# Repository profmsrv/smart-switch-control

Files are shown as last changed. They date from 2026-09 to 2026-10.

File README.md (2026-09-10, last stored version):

🏠 SmartHomePro
A smart home automation system built using ESP8266 and RS485 for reliable and scalable home control.

✨ Features
Wi-Fi based device control
ESP8266 based controllers
RS485 communication
Mobile and Web control
Physical switch control
Energy monitoring
Optional Firebase cloud integration
Secure user authentication
Scalable relay control
Local hotspot mode
⚙️ Technology
Microcontroller: ESP8266
Communication: RS485
Cloud: Firebase
Connectivity: Wi-Fi
Control: Mobile, Web & Physical Switches
🏗️ How It Works
The main ESP8266 controller communicates with multiple sub-controllers using RS485. Each sub-controller controls connected electrical loads through relays.

Mobile / Web
│
Wi-Fi
│
Main Controller
ESP8266
│
RS485
│
┌───┼────┬────┐
│ │ │ │
Sub Sub Sub Sub
│ │ │ │
Relay Relay Relay Relay
│ │ │ │
Loads Loads Loads Loads
⚡ Energy Monitoring
Monitor current and power consumption of connected electrical loads to understand usage and improve energy efficiency.

☁️ Firebase
Optional Firebase integration allows remote control, authentication, and real-time system monitoring from anywhere.

🚀 Getting Started
Clone this repository.
Open the ESP8266 project in Arduino IDE.
Install the required libraries.
Configure Wi-Fi and Firebase settings.
Upload the firmware to the ESP8266.
Connect the controllers using RS485.
Connect and configure the relay outputs.
⚠️ Safety
This project may involve high-voltage electrical systems. Electrical wiring and installation should only be performed by a qualified professional.

📌 Project Status
🚧 Under Development

❤️ About
SmartHomePro is designed to provide reliable, scalable, and energy-efficient smart home automation using affordable embedded hardware.

Made with ❤️ in India 🇮🇳

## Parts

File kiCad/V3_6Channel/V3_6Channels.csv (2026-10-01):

item number | Designator | Qty | Description_1 | MP | Package | Value | Assembly Instructions
1 | C1,C2 | 2 | 22 pF ±2% 50V Ceramic Capacitor C0G, NP0 0603 (1608 Metric) | CC0603GRNPO9BN220 | 0603 Yageo | crystal_cap
2 | C3 | 1 | 100nF±10% 10Vdc General Purpose Caps X7R 0402 (1005 Metric) | 0402B104K100CT | 402-2 WALSIN | vcc_de_cap
3 | C4 | 1 | 100nF±10% 10Vdc General Purpose Caps X7R 0402 (1005 Metric) | 0402B104K100CT | 402-2 WALSIN | avcc_de_cap
4 | C5 | 1 | 100nF±10% 10Vdc General Purpose Caps X7R 0402 (1005 Metric) | 0402B104K100CT | 402-2 WALSIN | aref_de_cap
5 | C6 | 1 | 100nF±10% 10Vdc General Purpose Caps X7R 0402 (1005 Metric) | 0402B104K100CT | 402-2 WALSIN | rst_de_cap
6 | C7 | 1 | 100nF±10% 10Vdc General Purpose Caps X7R 0402 (1005 Metric) | 0402B104K100CT | 402-2 WALSIN | max_de_cap
7 | C8 | 1 | 100nF±10% 10Vdc General Purpose Caps X7R 0402 (1005 Metric) | 0402B104K100CT | 402-2 WALSIN | uln_de_cap
8 | C9,C10,C11,C12,C13,C14 | 6 | ALU Electrolytic, SMD, EXV, +105°C, 25VDC, 5µF, 5 x 5.4 | KEMET EXV226M025A9DAA | EXV226M025A9DAA | Radial KEMET | AC Ripple Filter
9 | D1 | 1 | 600W, 15V, Bidirectional, TVS | SMBJ15CA | SMB Taiwan Semiconductor | SMBJ15CA
10 | J1,J11,J12 | 3 | Connector Header Through Hole 6 position 0.100 (2.54mm) | 61300611121 | None | 61300611121
11 | J2,J13 | 2 | Connector Header Through Hole 2 position 0.100 (2.54mm) | 61300211121 | None | 2Pin_jumper
12 | J3 | 1 | TERMI-BLOK PCB SIDE ENTRY STAC | TE Connectivity 284391-3 | 284391-3 | None | 284391-3
13 | J5 | 1 | 7 pins, 1 row, straight, gold plating | 61300711121 | None | 61300711121
14 | J14 | 1 | 6 Position Wire to Board Terminal Block Horizontal with Board 0.200 (5.08mm) Through Hole | 282837-6 | None | 282837-6
15 | P1 | 1 | Terminal Block Connector Wire Receptacle 2 5.08 mm 30-16 AWG Green 13.5 A 250 V | TE Connectivity 282837-2 | 282837-2 | None | AC IN
16 | PS1 | 1 | The HLK-PM01 is a small size low cost AC to DC converter which can take in 110V/220V AC at 50/60 Hz and give 5V 3W output. The module is can be used in designs which run on 5V and needs to be powered form the AC mains. | hlk-pm01 | None | HLK-PM01
17 | Q1 | 1 | 50-V, 7-ch darlington transistor array, -20C to 70C | ULN2003AN | PDIP-16 Texas Instruments | ULN2003AN
18 | R1,R5,R6,R11,R12,R15,R16,R19,R20,R23,R24,R27,R28 | 13 | Res Thick Film 0805 10K Ohm 5% 0.125W(1/8W) 200ppm/C Pad SMD Automotive T/R | RMCF0805JT10K0 | 0805 | 10k
19 | R2 | 1 | Res Thick Film 1206 120 Ohm 1% 0.25W 100ppm/C Molded SMD Paper T/R | RMCF1206FT120R | 1206 | 120
20 | R3,R4 | 2 | """Fixed Resistor, Thin Film, 0.25W, 10ohm, 200V, 1% +/-Tol, 100ppm/Cel, Surface Mount, 0805""" | RNCP0805FTD10R0 | 0805 | 10
21 | R7,R8,R9,R10,R13,R14,R17,R18,R21,R22,R25,R26 | 12 | 27.4 kOhms ±0.5% 1W Chip Resistor 1206 (3216 Metric) Anti-Sulfur, Automotive AEC-Q200, Moisture Resistant Thin Film | HRG3216P-2702-D-T1 | 3216 Susumu | HRG3216P-2702-D-T1
22 | U1 | 1 | 1/1 Transceiver Half RS422, RS485 8-SOIC | MAX485ESA+ | SOIC-8 Maxim | MAX485ESA_
23 | U2,U4,U5,U6,U7,U8 | 6 | Optoisolator Transistor with Base Output 4170Vrms 1 Channel 6-DIP | H11AA1M | PDIP-6 ON Semiconductor | H11AA1M
24 | U3 | 1 | MCU 8-bit - AVR ATmega Family ATmega328 Series Microcontrollers - 20 MHz - 32 KB - 2 KB - 32 Pins. | ATMEGA328P-AU | TQFP-32 Microchip | ATMEGA328P-AU
25 | Y1 | 1 | Crystal 16MHz ±10ppm (Tol) ±20ppm (Stability) 18pF FUND 70Ohm 4-Pin Ultra Mini-CSMD T/R | ABM8-16.000MHZ-D1X-T | NON-STANDARD-4 ABRACON | 16MHz

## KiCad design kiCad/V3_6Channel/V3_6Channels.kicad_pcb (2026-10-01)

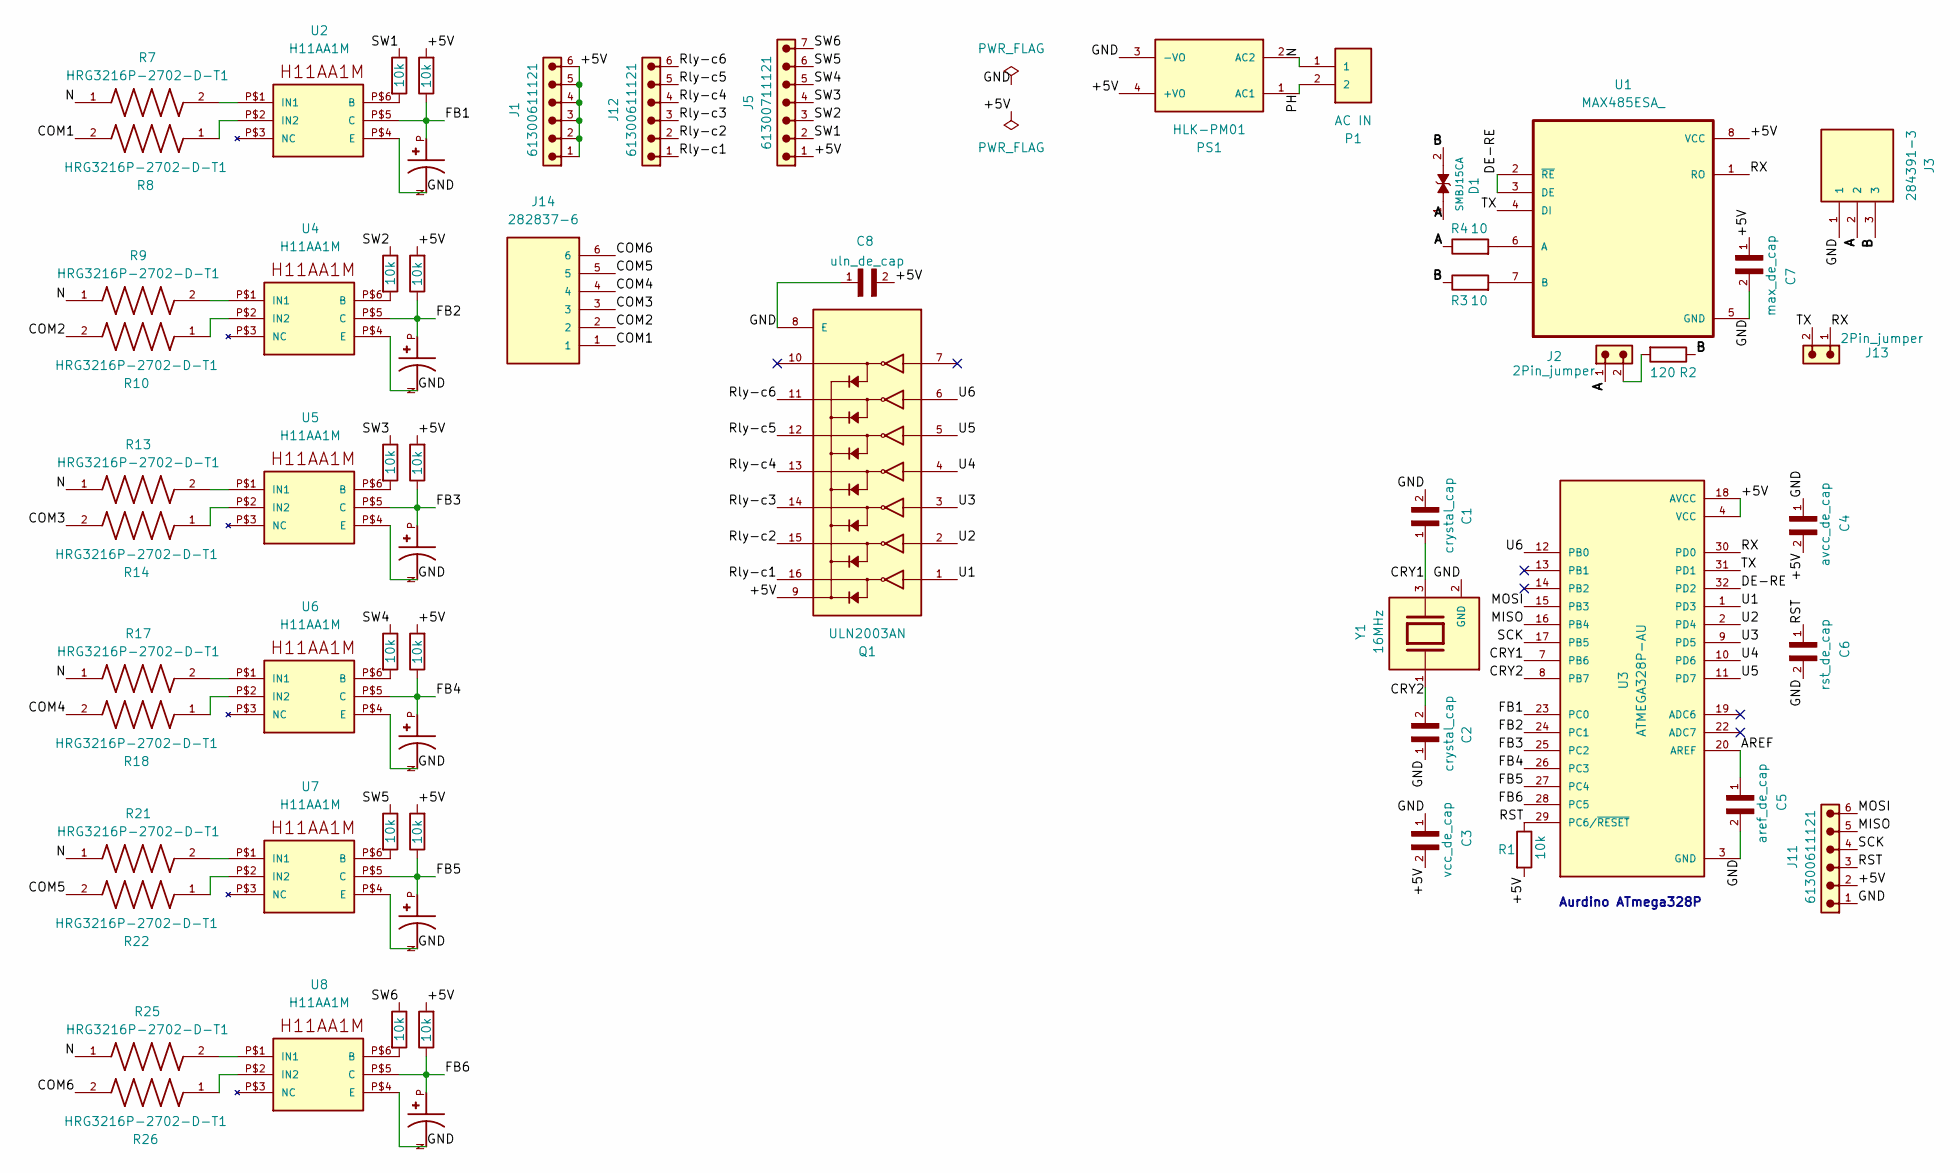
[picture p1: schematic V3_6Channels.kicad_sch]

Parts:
C1, C2: crystal_cap; CAPC1608X90
C3: vcc_de_cap; CAPC1005X55N; PARTREV Jul. 2024
C4: avcc_de_cap; CAPC1005X55N; PARTREV Jul. 2024
C5: aref_de_cap; CAPC1005X55N; PARTREV Jul. 2024
C6: rst_de_cap; CAPC1005X55N; PARTREV Jul. 2024
C7: max_de_cap; CAPC1005X55N; PARTREV Jul. 2024
C8: uln_de_cap; CAPC1005X55N; PARTREV Jul. 2024
C9, C10, C11, C12, C13, C14: AC Ripple Filter; CAPAE530X565N; PARTREV 7/13/2023
D1: SMBJ15CA; DIOM4336X265N; PARTREV I2102
J1, J11, J12: 61300611121
J2, J13: 2Pin_jumper; 61300211121
J3: 284391-3; TE_284391-3; PARTREV R
J5: 61300711121
J14: 282837-6; TE_282837-6; PARTREV R
P1: AC IN; TE_282837-2; PARTREV G3
PS1: HLK-PM01; CONV_HLK-PM01
Q1: ULN2003AN; DIP794W45P254L1969H508Q16; PARTREV P
R1, R5, R6, R11, R12, R15, R16, R19, R20, R23, R24, R27, R28: 10k; RESC2012X65N
R2: 120; RESC3216X70N
R3, R4: 10; RESC2012X60N
R7, R8, R9, R10, R13, R14, R17, R18, R21, R22, R25, R26: HRG3216P-2702-D-T1; RESC3216X55N
U1: MAX485ESA_; SOIC127P600X175-8N
U2, U4, U5, U6, U7, U8: H11AA1M; DIP6
U3: ATMEGA328P-AU; QFP80P900X900X120-32N; PARTREV 8271A
Y1: 16MHz; XTAL_ABM8-16.000MHz-D1X-T; PARTREV 44041

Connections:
/A: D1.1, J2.1, J3.2, R4.1
/AREF: C5.1, U3.20 (AREF)
/B: D1.2, J3.3, R2.1, R3.1
/COM1: J14.1, R8.2
/COM2: J14.2, R10.2
/COM3: J14.3, R14.2
/COM4: J14.4, R18.2
/COM5: J14.5, R22.2
/COM6: J14.6, R26.2
/CRY1: C1.1, U3.7 (PB6), Y1.3
/CRY2: C2.2, U3.8 (PB7), Y1.1
/DE-RE: U1.2 (~RE), U1.3 (DE), U3.32 (PD2)
/FB1: C9.P, R5.1, U2.P$5 (C), U3.23 (PC0)
/FB2: C10.P, R12.1, U3.24 (PC1), U4.P$5 (C)
/FB3: C11.P, R16.1, U3.25 (PC2), U5.P$5 (C)
/FB4: C12.P, R20.1, U3.26 (PC3), U6.P$5 (C)
/FB5: C13.P, R24.1, U3.27 (PC4), U7.P$5 (C)
/FB6: C14.P, R28.1, U3.28 (PC5), U8.P$5 (C)
/MISO: J11.5, U3.16 (PB4)
/MOSI: J11.6, U3.15 (PB3)
/N: P1.1, PS1.2 (AC2), R7.1, R9.1, R13.1, R17.1, R21.1, R25.1
/PH: P1.2, PS1.1 (AC1)
/RST: C6.1, J11.3, R1.1, U3.29 (PC6/~RESET)
/RX: J13.1, U1.1 (RO), U3.30 (PD0)
/Rly-c1: J12.1, Q1.16
/Rly-c2: J12.2, Q1.15
/Rly-c3: J12.3, Q1.14
/Rly-c4: J12.4, Q1.13
/Rly-c5: J12.5, Q1.12
/Rly-c6: J12.6, Q1.11
/SCK: J11.4, U3.17 (PB5)
/SW1: J5.2, R6.1
/SW2: J5.3, R11.1
/SW3: J5.4, R15.1
/SW4: J5.5, R19.1
/SW5: J5.6, R23.1
/SW6: J5.7, R27.1
/TX: J13.2, U1.4 (DI), U3.31 (PD1)
/U1: Q1.1, U3.1 (PD3)
/U2: Q1.2, U3.2 (PD4)
/U3: Q1.3, U3.9 (PD5)
/U4: Q1.4, U3.10 (PD6)
/U5: Q1.5, U3.11 (PD7)
/U6: Q1.6, U3.12 (PB0)
GND: C1.2, C2.1, C3.1, C4.1, C5.2, C6.2, C7.2, C8.1, C9.N, C10.N, C11.N, C12.N, C13.N, C14.N, J3.1, J11.1, PS1.3 (-VO), Q1.8 (E), U1.5 (GND), U2.P$4 (E), U3.3 (GND), U3.5 (GND), U3.21 (GND), U4.P$4 (E), U5.P$4 (E), U6.P$4 (E), U7.P$4 (E), U8.P$4 (E), Y1.2 (GND), Y1.4 (GND)
unnamed: J2.2, R2.2
unnamed: R4.2, U1.6 (A)
unnamed: R3.2, U1.7 (B)
unnamed: R6.2, U2.P$6 (B)
unnamed: R7.2, U2.P$1 (IN1)
unnamed: R8.1, U2.P$2 (IN2)
unnamed: R11.2, U4.P$6 (B)
unnamed: R9.2, U4.P$1 (IN1)
unnamed: R10.1, U4.P$2 (IN2)
unnamed: R15.2, U5.P$6 (B)
unnamed: R13.2, U5.P$1 (IN1)
unnamed: R14.1, U5.P$2 (IN2)
unnamed: R19.2, U6.P$6 (B)
unnamed: R17.2, U6.P$1 (IN1)
unnamed: R18.1, U6.P$2 (IN2)
unnamed: R23.2, U7.P$6 (B)
unnamed: R21.2, U7.P$1 (IN1)
unnamed: R22.1, U7.P$2 (IN2)
unnamed: R27.2, U8.P$6 (B)
unnamed: R25.2, U8.P$1 (IN1)
unnamed: R26.1, U8.P$2 (IN2)
VCC: C3.2, C4.2, C7.1, C8.2, J1.1, J1.2, J1.3, J1.4, J1.5, J1.6, J5.1, J11.2, PS1.4 (+VO), Q1.9, R1.2, R5.2, R12.2, R16.2, R20.2, R24.2, R28.2, U1.8 (VCC), U3.4 (VCC), U3.6 (VCC), U3.18 (AVCC)

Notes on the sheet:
Aurdino ATmega328P

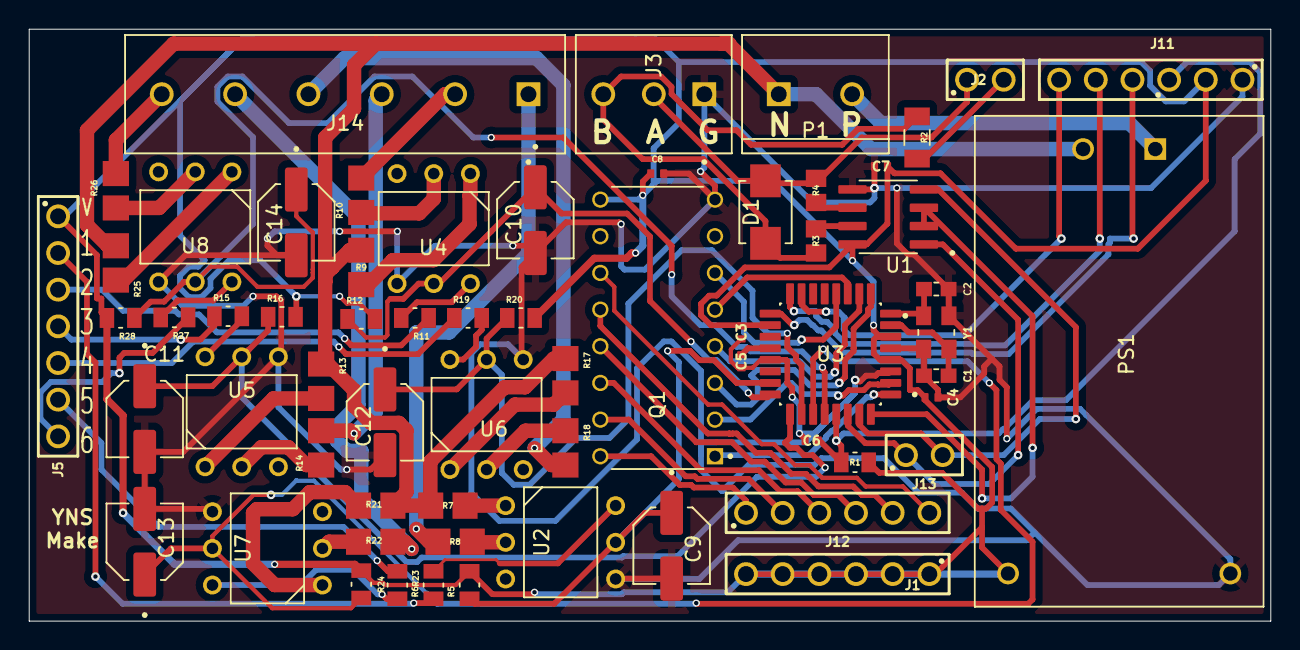
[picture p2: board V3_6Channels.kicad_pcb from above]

Board: 2 copper layers, 86.0 x 41.0 mm, 63 parts (0 on the bottom side), 67 nets.

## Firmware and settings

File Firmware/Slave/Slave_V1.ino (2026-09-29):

#include <SoftwareSerial.h>
#include <EEPROM.h>

// RS485 Pins for Pro Mini
#define RS485_RX_PIN    11
#define RS485_TX_PIN    10
#define RS485_DERE_PIN  12
#define SYNC_INTERVAL_MS  600000UL  // 10 minutes

const uint8_t BOARD_ID    = 6;
const bool DEFAULT_FEEDBACK_VALUE = HIGH; 
const uint8_t CONTROLLER_TYPE = 1; // 1 = one-way, 2 = two-way

SoftwareSerial rs485(RS485_RX_PIN, RS485_TX_PIN);
uint8_t g_yy, g_mm, g_dd, g_hh, g_min, g_sec;
bool g_timeReady = false;
unsigned long lastTickMillis  = 0;
unsigned long lastSyncRequest = 0;
const uint8_t RELAY_COUNT = 6;
const uint8_t RELAY_PINS[RELAY_COUNT]    = {2, 3, 4, 5, 6, 7};
const uint8_t FEEDBACK_PINS[RELAY_COUNT] = {A0, A1, A2, A3, A4, A5};
bool prevFeedbackState[RELAY_COUNT];
bool feedbackInitialized = false;
bool relayState[RELAY_COUNT] = {false}; // track current relay states

unsigned long cycleLastMillis[6] = {0};
struct TimerEntry {
  uint8_t mode;       // 1=once, 2=daily, 3=cycle

  uint8_t ONyear;
  uint8_t ONmonth;
  uint8_t ONdate;
  uint8_t ONhour;
  uint8_t ONmin;

  uint8_t OFFyear;
  uint8_t OFFmonth;
  uint8_t OFFdate;
  uint8_t OFFhour;
  uint8_t OFFmin;

  uint8_t cycle;      // repeat count for mode 3
  bool    active;     // 1=active, 0=deactivated

  // uint8_t cyclePhase;       // mode3: 0=ON phase, 1=OFF phase
  // unsigned long cycleLastMillis;  // mode3/4: millis timestamp of last phase start
};

struct SlaveConfig {
  bool        relayStates[6];   // existing key
  TimerEntry  timer[6];         // R1→timer[0] ... R6→timer[5]
};

SlaveConfig slaveConfig;

void syncTime(uint8_t* buffer);
void tickClock();
void checkSerialCommands();
void sendSystemCode(String codeStr);
void handlePacket();
void initFeedback();
void readFeedback();
void initRelayPins();
void controlRelay(uint8_t board, uint8_t ctrl, uint8_t state);
void restoreRelayStates();
void saveRelayStates();
void executeTimers(); 

void setup() {
  Serial.begin(115200);
  rs485.begin(9600);

  pinMode(RS485_DERE_PIN, OUTPUT);
  digitalWrite(RS485_DERE_PIN, LOW); // Set to RECEIVE mode

  Serial.println("--- RS485 SLAVE READY ---");

  sendSystemCode("888");
  initFeedback();   initRelayPins();    restoreRelayStates();

}

void loop() {
  if (rs485.available() > 0) {
    if (rs485.read() == 0x7E) handlePacket();
  }
  checkSerialCommands();
  tickClock();  
  readFeedback();
}

void checkSerialCommands() {
  if (Serial.available() > 0) {
    String input = Serial.readStringUntil('\n');
    input.trim(); // Remove spaces or \r
    if (input == "time") {
      if (!g_timeReady) {
        Serial.println("⚠️ Time not synced yet");
      } else {
        char timeStr[40];
        sprintf(timeStr, "20%02d-%02d-%02d %02d:%02d:%02d",
                g_yy, g_mm, g_dd, g_hh, g_min, g_sec);
        Serial.print("🕒 Current Time: ");
        Serial.println(timeStr);
      }
    }
    // Check if input starts with "c-"
    if (input.startsWith("c-")) {
      // Extract the code (everything after "c-")
      String codeValue = input.substring(2); 
      
      Serial.print("🛠 Command detected. Sending Code: ");
      Serial.println(codeValue);

      // Call the RS485 send function
      sendSystemCode(codeValue);
    }
    if (input.startsWith("t-")) {
      uint8_t ctrl = input.substring(2).toInt();
      if (ctrl < 1 || ctrl > RELAY_COUNT) {
        Serial.println("⚠️ Invalid controller number");
        return;
      }
      uint8_t slot = ctrl - 1;
      TimerEntry& t = slaveConfig.timer[slot];

      Serial.print("⏱ Timer R"); Serial.print(ctrl);
      Serial.print(" | Active: "); Serial.print(t.active ? "YES" : "NO");
      Serial.print(" | Mode: "); Serial.println(t.mode);

      if (!t.active) return;

      if (t.mode == 1) {
        Serial.print("  Action: "); Serial.println(t.cycle ? "ON" : "OFF");
        Serial.print("  Time: 20"); Serial.print(t.ONyear); Serial.print("-");
        Serial.print(t.ONmonth); Serial.print("-"); Serial.print(t.ONdate);
        Serial.print(" "); Serial.print(t.ONhour); Serial.print(":"); Serial.println(t.ONmin);
      }
      else if (t.mode == 2) {
        Serial.print("  ON:  "); Serial.print(t.ONhour); Serial.print(":"); Serial.println(t.ONmin);
        Serial.print("  OFF: "); Serial.print(t.OFFhour); Serial.print(":"); Serial.println(t.OFFmin);
      }
      else if (t.mode == 3) {
        Serial.print("  ON dur:  "); Serial.print(t.ONmin); Serial.println(" min");
        Serial.print("  OFF dur: "); Serial.print(t.OFFmin); Serial.println(" min");
        Serial.print("  Repeat:  "); Serial.println(t.cycle);
      }
      else if (t.mode == 4) {
        Serial.print("  Action: "); Serial.println(t.cycle ? "ON after OFF" : "OFF after ON");
        Serial.print("  Delay:  "); Serial.print(t.ONmin); Serial.println(" min");
      }
    }
  }
}

void syncTime(uint8_t* buffer) {
  g_yy  = buffer[1];
  g_mm  = buffer[2];
  g_dd  = buffer[3];
  g_hh  = buffer[4];
  g_min = buffer[5];
  g_sec = buffer[6];
  g_timeReady = true;

  char timeStr[40];
  sprintf(timeStr, "20%02d-%02d-%02d %02d:%02d:%02d",
          g_yy, g_mm, g_dd, g_hh, g_min, g_sec);
  Serial.print("🕒 Time Synced: ");
  Serial.println(timeStr);
}

void tickClock() {
  if (!g_timeReady) return;
  unsigned long now = millis();
  // --- Tick every 1 second ---
  if (now - lastTickMillis >= 1000) {
    lastTickMillis = now;

    g_sec++;
    if (g_sec >= 60) { g_sec = 0; g_min++; }
    if (g_min >= 60) { g_min = 0; g_hh++;  }
    if (g_hh  >= 24) { g_hh  = 0; g_dd++;  }
    // Note: skipping month/year overflow — master re-sync handles accuracy
    executeTimers();
  }
  // --- Request re-sync every 10 minutes ---
  if (now - lastSyncRequest >= SYNC_INTERVAL_MS) {
    lastSyncRequest = now;
    Serial.println("🔄 Requesting time re-sync from master...");
    sendSystemCode("888");
  }
}

void sendSystemCode(String codeStr) {
  int code = codeStr.toInt(); // String "100" becomes int 100
  
  uint8_t packet[7];
  packet[0] = 0x7E;          // Start Byte
  packet[1] = 0x03;          // Type 3: System/ACK Communication
  
  // High byte and Low byte (Split 16-bit int into two 8-bit bytes)
  packet[2] = (code >> 8) & 0xFF; 
  packet[3] = code & 0xFF;
  
  // Checksum (XOR Type, High Byte, Low Byte)
  uint8_t checksum = 0;
  for (int i = 1; i <= 3; i++) {
    checksum ^= packet[i];
  }
  packet[4] = checksum;
  packet[5] = 0x7F;          // End Byte
  packet[6] = 0x00;          // Padding

  // RS485 Send Logic
  digitalWrite(RS485_DERE_PIN, HIGH); // Switch to Transmit
  delayMicroseconds(100);
  
  rs485.write(packet, 7);
  rs485.flush();
  
  delayMicroseconds(100);
  digitalWrite(RS485_DERE_PIN, LOW);  // Switch back to Receive
  
  Serial.print("📤 Sent System Code: ");
  Serial.println(code);
}

void handlePacket() {
  uint8_t buffer[20];
  uint8_t idx = 0;
  delay(30);
  while (rs485.available() > 0 && idx < 20) {
    uint8_t b = rs485.read();
    if (b == 0x7F) break;  // End byte — stop, don't store it
    buffer[idx++] = b;
  }
  // Now buffer = [TYPE][DATA...][CHECKSUM]// idx = total bytes including checksum
  if (idx < 2) {
    Serial.println("❌ Packet too short");
    return;
  }
  uint8_t type             = buffer[0];
  uint8_t receivedChecksum = buffer[idx - 1];  // ✅ Last byte is checksum
  // XOR from TYPE to last DATA byte (exclude checksum itself)
  uint8_t calculatedChecksum = 0;
  for (int i = 0; i < idx - 1; i++) {
    calculatedChecksum ^= buffer[i];
  }
  if (calculatedChecksum != receivedChecksum) {
    Serial.println("❌ Checksum Error!");
    Serial.print("Expected: "); Serial.print(calculatedChecksum, HEX);
    Serial.print(" Got: "); Serial.println(receivedChecksum, HEX);
    return;
  }

  Serial.print("✅ Packet [Type 0x0");  Serial.print(type, HEX);  Serial.println("]");

  if (type == 0x01) {
    // [TYPE][B][C][S][CHKSUM] → idx=5
    Serial.print("Board: "); Serial.print(buffer[1]);
    Serial.print(" | Ctrl: "); Serial.print(buffer[2]);
    Serial.print(" | State: "); Serial.println(buffer[3]);
    controlRelay(buffer[1], buffer[2], buffer[3]); 
  }

  else if (type == 0x02) {
    // [TYPE][MODE][B][C][ACTIVE][...data...][CHKSUM]
    uint8_t mode   = buffer[1];
    uint8_t board  = buffer[2];
    uint8_t ctrl   = buffer[3];
    uint8_t active = buffer[4];

    Serial.print("⏱ Timer | Mode: "); Serial.print(mode);
    Serial.print(" | Board: ");       Serial.print(board);
    Serial.print(" | Ctrl: ");        Serial.print(ctrl);
    Serial.print(" | Active: ");      Serial.println(active);

    if (board != BOARD_ID) { Serial.println("⚠️ Not for this board"); return; }
    if (ctrl < 1 || ctrl > RELAY_COUNT) { Serial.println("⚠️ Invalid ctrl"); return; }

    uint8_t slot = ctrl - 1;

    // If active=0 → deactivate and save
    if (active == 0) {
      slaveConfig.timer[slot].active = false;
      saveRelayStates();
      Serial.println("🗑 Timer deactivated");
      return;
    }

    // Fill timer slot based on mode
    slaveConfig.timer[slot].mode   = mode;
    slaveConfig.timer[slot].active = true;

    if (mode == 1) {
      // [ACTION][YY][MM][DD][HH][MIN]
      slaveConfig.timer[slot].ONyear  = buffer[5];  // action stored in ONyear: 1=ON 0=OFF
      slaveConfig.timer[slot].ONmonth = buffer[6];
      slaveConfig.timer[slot].ONdate  = buffer[7];
      slaveConfig.timer[slot].ONhour  = buffer[8];
      slaveConfig.timer[slot].ONmin   = buffer[9];
      // Serial.print("Mode1 | Action: "); Serial.print(buffer[5] ? "ON" : "OFF");
      // Serial.printf(" | Time: 20%02d-%02d-%02d %02d:%02d\n", buffer[6], buffer[7], buffer[8], buffer[9], buffer[10]);
      Serial.print("Mode1 | Action: "); Serial.print(buffer[5] ? "ON" : "OFF");
      Serial.print(" | Time: 20"); Serial.print(buffer[6]); Serial.print("-");
      Serial.print(buffer[7]); Serial.print("-"); Serial.print(buffer[8]);
      Serial.print(" "); Serial.print(buffer[9]); Serial.print(":"); Serial.println(buffer[10]);

      // fix: shift — action=buffer[5], YY=buffer[6]...MIN=buffer[10]
      slaveConfig.timer[slot].ONyear  = buffer[6];
      slaveConfig.timer[slot].ONmonth = buffer[7];
      slaveConfig.timer[slot].ONdate  = buffer[8];
      slaveConfig.timer[slot].ONhour  = buffer[9];
      slaveConfig.timer[slot].ONmin   = buffer[10];
      slaveConfig.timer[slot].cycle   = buffer[5]; // reuse cycle field to store action(1/0)
    }
    else if (mode == 2) {
      // [ONhour][ONmin][OFFhour][OFFmin]
      slaveConfig.timer[slot].ONhour  = buffer[5];
      slaveConfig.timer[slot].ONmin   = buffer[6];
      slaveConfig.timer[slot].OFFhour = buffer[7];
      slaveConfig.timer[slot].OFFmin  = buffer[8];
      // Serial.printf("Mode2 | ON: %02d:%02d OFF: %02d:%02d\n", buffer[5], buffer[6], buffer[7], buffer[8]);
      Serial.print("Mode2 | ON: "); Serial.print(buffer[5]); Serial.print(":");
      Serial.print(buffer[6]); Serial.print(" OFF: "); Serial.print(buffer[7]);
      Serial.print(":"); Serial.println(buffer[8]);
    }
    // else if (mode == 3) {
    //   // [ONmin][OFFmin][repeat]
    //   slaveConfig.timer[slot].ONmin  = buffer[5];  // ON duration minutes
    //   slaveConfig.timer[slot].OFFmin = buffer[6];  // OFF duration minutes
    //   slaveConfig.timer[slot].cycle  = buffer[7];  // repeat count
    //   slaveConfig.timer[slot].cyclePhase     = 0;
    //   slaveConfig.timer[slot].cycleLastMillis = millis();
    //   controlRelay(BOARD_ID, ctrl, 1); // start by turning ON immediately
    //   startMode3(slot);
    //   Serial.print("Mode3 | ON_dur: "); Serial.print(buffer[5]);
    //   Serial.print(" OFF_dur: "); Serial.print(buffer[6]);
    //   Serial.print(" Repeat: "); Serial.println(buffer[7]);
    // }
    else if (mode == 4) {
      // [ACTION][DELAY_MIN]
      slaveConfig.timer[slot].cycle  = buffer[5]; // reuse: 1=ON after off, 0=OFF after on
      slaveConfig.timer[slot].ONmin  = buffer[6]; // delay in minutes
      cycleLastMillis[slot] = millis(); // start countdown now
      Serial.print("Mode4 | Action: "); Serial.print(buffer[5] ? "ON after OFF" : "OFF after ON");
      Serial.print(" | Delay: "); Serial.print(buffer[6]); Serial.println(" min");
    }

    saveRelayStates();
    Serial.println("✅ Timer saved");
  }

  else if (type == 0x03) {
    // [TYPE][YY][MM][DD][HH][MIN][SEC][CHKSUM] → idx=8
    if (idx < 8) {  Serial.println("❌ Invalid Time Packet"); return; }
    char timeStr[40];
    sprintf(timeStr, "20%02d-%02d-%02d %02d:%02d:%02d",
            buffer[1], buffer[2], buffer[3],
            buffer[4], buffer[5], buffer[6]);
    Serial.print("🕒 Time Sync: ");
    Serial.println(timeStr); 
    syncTime(buffer);
  }
  // else if (type == 0x04) {
  //   // [TYPE][O][B][C][F][CHKSUM]
  //   Serial.print("o: "); Serial.print(buffer[1]);
  //   Serial.print(" | Board: "); Serial.print(buffer[2]);
  //   Serial.print(" | Ctrl: "); Serial.print(buffer[3]);
  //   Serial.print(" | f: "); Serial.println(buffer[4]);
  // }
}
  
// first of all make a struct like
// {
//   bool relayStates[6]; // OLD KEY
//   timer: {
//     R1: { // controler(c)
//       Mode, // 1-once 2-daily 3-cycle
//       ONmin,  OFFmin, // two digit numer
//       ONhour, OFFhour, // two digit numer
//       ONdate, OFFdate, // two digit numer
//       ONmonth,  OFFmonth, // two digit numer
//       ONyear, OFFyear, // two digit numer
//       cycle, // two digit numer
//     }
//     R2:{} R3:{} R4:{}  R5:{}  R6:{}
//     ex - 
//     data recived form mode 1 - {"b":10,"c":1,"m":1,"n":"2026-04-02T14:40","t":1} - n means on timer
//     {"b":10,"c":1,"f":"2026-04-02T14:43","m":1,"t":1} - f means off timer
//     data recived from mode 2 - {"b":10,"c":1,"f":"18:39","m":2,"n":"17:39","t":1}
//     data recived form mode 3 - {"b":10,"c":1,"f":"YYYY-MM-DDTHH:25","m":3,"n":"YYYY-MM-DDTHH:57","r":3,"t":1}
//     data recived form mode 4 - "{\"t\":1,\"n\":13,\"b\":10,\"c\":2,\"f\":0,\"m\":4}"; 
//     b- board, c- contorler (relay), f- off time, n- on time, m- mode, r- repeate times (cycles), t- timer state(1 mean active, 0 mean diactivate)

//   }

// }


void initFeedback() {
  // Summary of initFeedback()
  // Type    DefaultHIGH       DefaultLOW
  // Type1   INPUT_PULLUP✅    External pull-down resistor needed ⚠️
  // Type2   INPUT✅           INPUT ✅
  for (int i = 0; i < RELAY_COUNT; i++) {

    if (CONTROLLER_TYPE == 1) {
      // Physical switch — need pull resistor to hold default state
      if (DEFAULT_FEEDBACK_VALUE == HIGH) {
        pinMode(FEEDBACK_PINS[i], INPUT_PULLUP);  // floating → stays HIGH naturally
      } else {
        pinMode(FEEDBACK_PINS[i], INPUT);  // Pro Mini has no INPUT_PULLDOWN
        // ⚠️ For LOW default on type 1 — you need external pull-down resistor on hardware
      }
    } else {
      // Optocoupler — always drives pin actively, no floating issue
      pinMode(FEEDBACK_PINS[i], INPUT);
    }

    prevFeedbackState[i] = digitalRead(FEEDBACK_PINS[i]);
  }
  feedbackInitialized = true;
}

void initRelayPins(){
  for (int i = 0; i < RELAY_COUNT; i++) {
    pinMode(RELAY_PINS[i], OUTPUT);
    digitalWrite(RELAY_PINS[i], LOW);
    relayState[i] = false;
  }
}

void readFeedback() { 
  if (!feedbackInitialized) return;
  for (int i = 0; i < RELAY_COUNT; i++) {
    bool currentState = digitalRead(FEEDBACK_PINS[i]);
    if (currentState != prevFeedbackState[i]) {
      prevFeedbackState[i] = currentState;
      int ctrlNumber = i + 1;                          // A0→1, A1→2 ...
      int stateValue = (currentState != DEFAULT_FEEDBACK_VALUE) ? 1 : 0;
      // Build code: 6 + ID(2digit) + ctrl(1digit) + state(1digit)
      char code[8];
      sprintf(code, "6%02d%d%d", BOARD_ID, ctrlNumber, stateValue);
      Serial.print("🔁 Feedback Changed → Code: ");
      Serial.println(code);
      if (CONTROLLER_TYPE == 1) {
        controlRelay(BOARD_ID, ctrlNumber, stateValue);
      }
      sendSystemCode(String(code));
    }
  }

}

void controlRelay(uint8_t board, uint8_t ctrl, uint8_t state) {

  if (board != BOARD_ID) {
    Serial.println("⚠️ Packet not for this board, ignoring.");
    return;
  }
  if (ctrl < 1 || ctrl > RELAY_COUNT) {
    Serial.println("⚠️ Invalid controller number.");
    return;
  }
  uint8_t idx = ctrl - 1; // convert to 0-based index
  if (CONTROLLER_TYPE == 1) {
    // One-way: directly set relay based on state value
    if (state == 1) {
      relayState[idx] = true;
    } else {
      relayState[idx] = false;
    }

  } else if (CONTROLLER_TYPE == 2) {
    // Two-way: always toggle regardless of state value
    relayState[idx] = !relayState[idx];
  }
  // Apply to physical pin
  digitalWrite(RELAY_PINS[idx], relayState[idx] ? HIGH : LOW);
  saveRelayStates();
  Serial.print("🔌 Relay ");
  Serial.print(ctrl);
  Serial.print(" → ");
  Serial.println(relayState[idx] ? "ON" : "OFF");
}

void saveRelayStates() {
  for (int i = 0; i < RELAY_COUNT; i++) {
    slaveConfig.relayStates[i] = relayState[i];
  }
  EEPROM.put(0, slaveConfig);
}

void restoreRelayStates() {
  EEPROM.get(0, slaveConfig);
  for (int i = 0; i < RELAY_COUNT; i++) {
    relayState[i] = slaveConfig.relayStates[i];
    digitalWrite(RELAY_PINS[i], relayState[i] ? HIGH : LOW);
    Serial.print("🔁 Relay ");
    Serial.print(i + 1);
    Serial.print(" restored → ");
    Serial.println(relayState[i] ? "ON" : "OFF");
  }
}

void executeTimers() {
  if (!g_timeReady) return;

  for (uint8_t slot = 0; slot < RELAY_COUNT; slot++) {
    TimerEntry& t = slaveConfig.timer[slot];
    if (!t.active) continue;

    uint8_t ctrl = slot + 1;

    // ─── MODE 1 → ONCE ───────────────────────────────────────────
    if (t.mode == 1) {
      if (g_yy == t.ONyear && g_mm == t.ONmonth && g_dd == t.ONdate &&
          g_hh == t.ONhour && g_min == t.ONmin && g_sec == 0) {

        uint8_t action = t.cycle; // 1=ON, 0=OFF
        controlRelay(BOARD_ID, ctrl, action);
        t.active = false; // fire once then deactivate
        saveRelayStates();
        Serial.print("✅ Mode1 fired → R"); Serial.print(ctrl);
        Serial.println(action ? " ON" : " OFF");
      }
    }
    // ─── MODE 2 → DAILY ──────────────────────────────────────────
    else if (t.mode == 2) {
      if (g_sec == 0) { // check only on minute boundary
        if (g_hh == t.ONhour && g_min == t.ONmin) {
          controlRelay(BOARD_ID, ctrl, 1);
          Serial.print("✅ Mode2 ON fired → R"); Serial.println(ctrl);
        }
        else if (g_hh == t.OFFhour && g_min == t.OFFmin) {
          controlRelay(BOARD_ID, ctrl, 0);
          Serial.print("✅ Mode2 OFF fired → R"); Serial.println(ctrl);
        }
      }
    }
    // ─── MODE 3 → CYCLE ──────────────────────────────────────────
    // if (t.mode == 3) {
    //   if (g_sec == 0) { // check only on minute boundary
    //     if (g_hh == t.ONhour && g_min == t.ONdate) { // ONdate reused as trigger min

    //       if (t.cyclePhase == 0) {
    //         // was ON → turn OFF, next wait is OFFmin
    //         controlRelay(BOARD_ID, ctrl, 0);
    //         t.cyclePhase = 1;
    //         Serial.print("🔄 Mode3 OFF → R"); Serial.println(ctrl);

    //         // decrement cycle after each OFF
    //         if (t.cycle > 0) t.cycle--;
    //         if (t.cycle == 0) {
    //           t.active = false;
    //           saveRelayStates();
    //           Serial.print("✅ Mode3 complete → R"); Serial.println(ctrl);
    //           continue;
    //         }

    //         // calculate next ON time
    //         uint8_t nextMin  = g_min + t.OFFmin;
    //         uint8_t nextHour = g_hh;
    //         while (nextMin >= 60) { nextMin -= 60; nextHour++; }
    //         if (nextHour >= 24) nextHour -= 24;
    //         t.ONhour = nextHour;
    //         t.ONdate = nextMin;

    //       } else {
    //         // was OFF → turn ON, next wait is ONmin
    //         controlRelay(BOARD_ID, ctrl, 1);
    //         t.cyclePhase = 0;
    //         Serial.print("🔄 Mode3 ON → R"); Serial.println(ctrl);

    //         // calculate next OFF time
    //         uint8_t nextMin  = g_min + t.ONmin;
    //         uint8_t nextHour = g_hh;
    //         while (nextMin >= 60) { nextMin -= 60; nextHour++; }
    //         if (nextHour >= 24) nextHour -= 24;
    //         t.ONhour = nextHour;
    //         t.ONdate = nextMin;
    //       }

    //       saveRelayStates();
    //     }
    //   }
    // }
    // ─── MODE 4 → DELAYED SINGLE ACTION ──────────────────────────
    else if (t.mode == 4) {
      unsigned long now = millis();
      unsigned long elapsed = millis() - cycleLastMillis[slot]; // now - t.cycleLastMillis;

      if (elapsed >= (unsigned long)t.ONmin * 60000UL) {
        uint8_t action = t.cycle; // 1=ON after OFF, 0=OFF after ON
        controlRelay(BOARD_ID, ctrl, action);
        t.active = false;
        saveRelayStates();
        Serial.print("✅ Mode4 fired → R"); Serial.print(ctrl);
        Serial.println(action ? " ON" : " OFF");
      }
    }
  }
}

// void startMode3(uint8_t slot) {
//   TimerEntry& t = slaveConfig.timer[slot];
//   uint8_t ctrl  = slot + 1;

//   bool currentLoad = relayState[slot]; // true=ON, false=OFF

//   // Calculate next trigger time based on current state
//   uint8_t waitMin;
//   if (currentLoad) {
//     // Load is ON → wait ONmin then turn OFF
//     t.cyclePhase = 0; // 0 = currently ON, next action is OFF
//     waitMin = t.ONmin;
//   } else {
//     // Load is OFF → wait OFFmin then turn ON
//     t.cyclePhase = 1; // 1 = currently OFF, next action is ON
//     waitMin = t.OFFmin;
//   }

//   // Calculate next trigger time
//   uint8_t trigMin = g_min + waitMin;
//   uint8_t trigHour = g_hh;
//   while (trigMin >= 60) { trigMin -= 60; trigHour++; }
//   if (trigHour >= 24) trigHour -= 24;

//   // Store next trigger time in OFFhour/OFFmin temporarily
//   t.ONhour  = trigHour;  // reuse ONhour as next trigger hour
//   t.ONdate  = trigMin;   // reuse ONdate as next trigger min
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

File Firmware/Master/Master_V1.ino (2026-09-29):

#include <ESP8266WiFi.h>
#include <ESP8266WebServer.h>
#include <ESP8266mDNS.h>
#include <EEPROM.h>
#include <ArduinoJson.h>        
#include <FirebaseESP8266.h>    
#include <SoftwareSerial.h>   
#include <time.h>

ESP8266WebServer server(80);

// RS485 Pins
#define RS485_RX_PIN    D5
#define RS485_TX_PIN    D6
#define RS485_DERE_PIN  D7

// ultra version
// Object Instances
// Fixed: Pass pins to constructor here
SoftwareSerial rs485Serial(RS485_RX_PIN, RS485_TX_PIN); 
FirebaseData fbdoStream;
FirebaseAuth auth;
FirebaseConfig fbConfig;
FirebaseData fbdoWrite;

// Fixed: Renamed from 'Config' to 'DeviceConfig' to avoid SoftwareSerial conflict
struct DeviceConfig {
  char ap_ssid[20]; 
  char ap_pass[20];
  char sta_ssid[20];
  char sta_pass[20];  
  char api_key[50];
  char db_url[100];  
  char fb_email[64];      
  char fb_pass[32];        
  char fb_auth_mode[16];
};
DeviceConfig devData; 

// Function declarations
void ProcessCmd(String input);
void readSerial();
void setupWifi();
void setupServer();   
void setCORSHeaders();  
void streamCallback(StreamData data);  
void streamTimeoutCallback(bool timeout); 
void setupFb();
void Tcommunication(String jsonData);
void parseTime(String iso, uint8_t *out);
void initTime(); 
void readFromSlave();
void sendRealTimeToSlave();

bool isFbInitialStreamCompleated = false;

void setup(){
  Serial.begin(115200); 
  Serial.println("\n--- SMART SWITCH CONTROL ---");
  
  rs485Serial.begin(9600); 

  pinMode(RS485_DERE_PIN, OUTPUT);
  digitalWrite(RS485_DERE_PIN, LOW);

  EEPROM.begin(sizeof(DeviceConfig)); 
  EEPROM.get(0, devData);
  
  if(!(strlen(devData.ap_ssid) > 0)){
    strncpy(devData.ap_ssid, "msrv", sizeof(devData.ap_ssid) - 1);
    strncpy(devData.ap_pass, "12345678", sizeof(devData.ap_pass) - 1);
    EEPROM.put(0, devData);
    EEPROM.commit(); 
  }

  setupWifi();
  
  if(MDNS.begin("ssc")) {
    Serial.println("mDNS started: http://ssc.local");
  }
  
  setupServer();
  
  if(WiFi.status() == WL_CONNECTED){
    setupFb();
    initTime();
    sendRealTimeToSlave();
  } 
}

void loop(){
  readSerial();
  readFromSlave();
  server.handleClient();
  MDNS.update();

  // Keep Firebase stream alive
  if (Firebase.ready()) {
    Firebase.readStream(fbdoStream);

    if (!fbdoStream.httpConnected()) {
      Serial.println("⚠️ Stream disconnected. Reconnecting...");
      Firebase.beginStream(fbdoStream, "/Stream");
    }
  }
}

void readFromSlave() {
  // Check if there is at least something in the buffer
  if (rs485Serial.available() > 0) {
    // 1. Look for Start Byte
    if (rs485Serial.peek() == 0x7E) {  

      unsigned long startWait = millis();
      while (rs485Serial.available() < 7 && millis() - startWait < 50) {
        delay(1); 
      }

      if (rs485Serial.available() >= 7) {
        rs485Serial.read(); // Actually consume the 0x7E we peeked at
        uint8_t type = rs485Serial.read();
        uint8_t high = rs485Serial.read();
        uint8_t low  = rs485Serial.read();
        uint8_t chk  = rs485Serial.read();
        uint8_t end  = rs485Serial.read();
        uint8_t pad  = rs485Serial.read(); // Read the padding byte too
        uint8_t calcChk = type ^ high ^ low; // 3. Verify Checksum (Type ^ High ^ Low)
        if (type == 0x03 && chk == calcChk && end == 0x7F) {
          int receivedCode = (high << 8) | low;
          Serial.printf("📩 Received System Code: %d\n", receivedCode);
          String codeStr = String(receivedCode);

          if(receivedCode == 888) { sendRealTimeToSlave(); } // for real time

          if (codeStr[0] == '6' && codeStr.length() == 5) {
              int b = codeStr.substring(1, 3).toInt(); // Board ID
              int c = codeStr.substring(3, 4).toInt(); // Controller ID
              int a = codeStr.substring(4).toInt();    // Action/State

              Serial.println("✅ ACK Received");
              Serial.printf("b: %d, c: %d, a: %d\n", b, c, a);

              // Dynamic Path build cheyadam: "/BoardID/ControllerID/a"
              String path = "/" + String(b) + "/" + String(c) + "/a";

              if (Firebase.ready()) {
                  // Ikkada path "/12/3/a" format lo veltundi, value 'a' update avtundi
                  if (Firebase.setInt(fbdoWrite, path, a)) {
                      Serial.print("✅ Firebase updated at: ");
                      Serial.println(path);
                  } else {
                      Serial.println("❌ Firebase write failed");
                      Serial.println(fbdoWrite.errorReason());
                  }
              }
          }

        } else {
          Serial.println("❌ Data Corrupted or Checksum Failed");
        }
      }
    } else {
      // If the first byte isn't 0x7E, clear it to find the next valid start
      rs485Serial.read(); 
    }
  }
}
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
